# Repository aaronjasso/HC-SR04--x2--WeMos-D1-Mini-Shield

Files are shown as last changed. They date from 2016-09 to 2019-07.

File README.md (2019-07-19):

# HC-SR04--x2--WeMos-D1-Mini-Shield
Shield to attach up to two HC-SR04 ultrasonic distance sensors to a Wemos D1 Mini ESP8266 module.

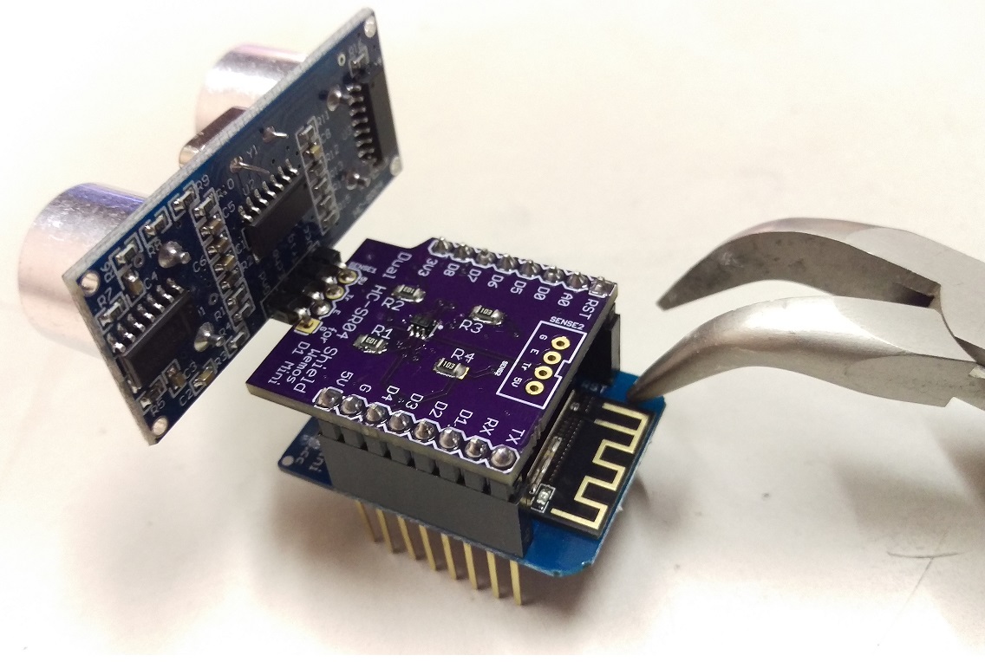
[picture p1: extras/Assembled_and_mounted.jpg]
Assembled Board with SENSE1, mounted to a Wemos D1 Mini


[Sensor datasheet](https://cdn.sparkfun.com/datasheets/Sensors/Proximity/HCSR04.pdf)

[Second datasheet source](https://www.electroschematics.com/8902/hc-sr04-datasheet/)

Works with one or two sensors. The first is mounted to the shield, the second is intended to be mounted elsewhere and connected with a four-conductor cable. It could also be mounted directly to the board facing the opposite direction as the first sensor.

Utilizes a BS138DW SOT-363 chip (which is just two BSS138 N-channel enhanced mode MOSFETs in one package) for level switching the ESP8266's 3.3V trigger pulse up to 5V for the sensors (ref: https://learn.sparkfun.com/tutorials/retired---using-the-logic-level-converter). The down-convert is a simple voltage divider.

All resistors are 0805 size. Resistors on top of board (with the IC) are 10K, resistors on bottom are 20K.

SENSE1 is mounted to the board  
Trigger pin:  D3  
Echo pin:  D4

SENSE2 (optional) can be located off-board  
Trigger pin:  D7  
Echo pin:  D8

The board and SENSE1 have been tested. Example Arduino sketches are in work. Boards available from OSH Park here: https://oshpark.com/shared_projects/YeCIIDGi

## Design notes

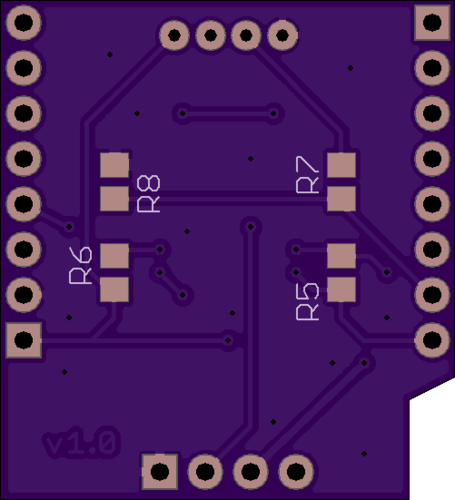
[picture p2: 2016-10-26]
extras/HC-SR04 Shield bottom.png

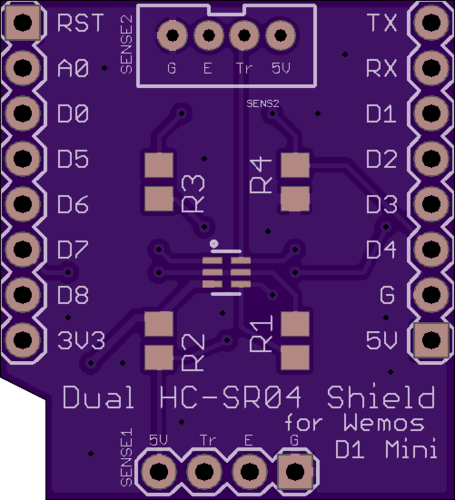
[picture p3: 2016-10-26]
extras/HC-SR04 Shield top.png

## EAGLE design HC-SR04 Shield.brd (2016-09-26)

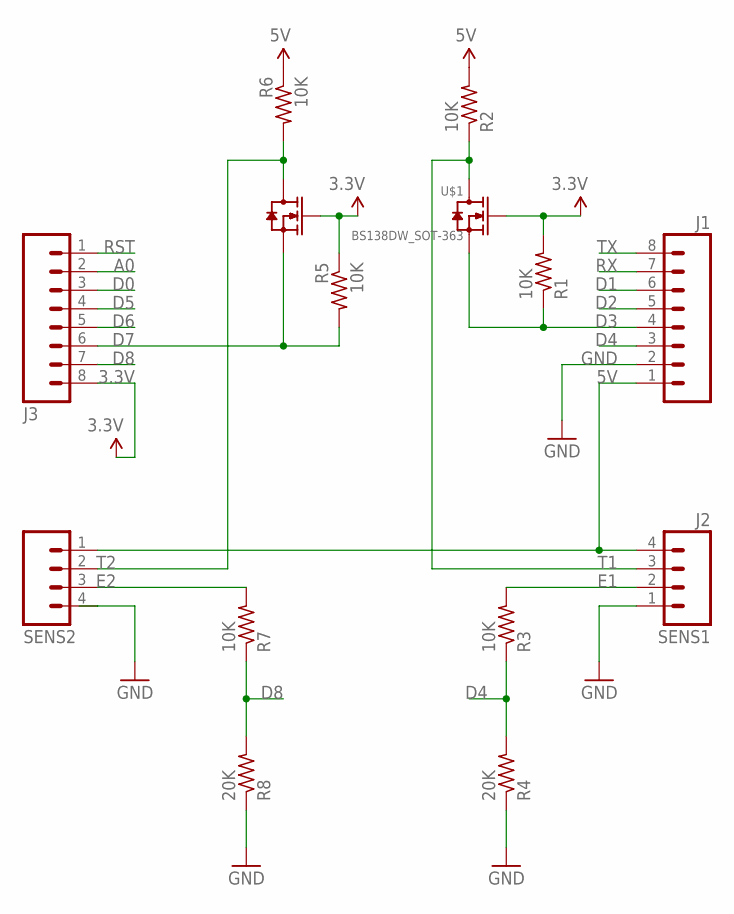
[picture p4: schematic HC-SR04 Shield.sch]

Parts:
J1, J3: M08SILK_FEMALE_PTH; 1X08
J2: SENS1; 1X04
R1, R2, R3, R5, R6, R7: 10K; R0805
R4, R8: 20K; R0805
SENS2: M04JST-PTH-VERT; JST-4-PTH-VERT
U$1: BS138DW_SOT-363; SOT363

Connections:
3.3V: J3.8, R1.2, R5.1, U$1.2 (G1), U$1.5 (G)
5V: J1.1, J2.4, R2.2, R6.1, SENS2.1
A0: J3.2
D0: J3.3
D1: J1.6
D2: J1.5
D3: J1.4, R1.1, U$1.4 (S)
D4: J1.3, R3.1, R4.2
D5: J3.4
D6: J3.5
D7: J3.6, R5.2, U$1.1 (S1)
D8: J3.7, R7.1, R8.2
E1: J2.2, R3.2
E2: R7.2, SENS2.3
GND: J1.2, J2.1, R4.1, R8.1, SENS2.4
RST: J3.1
RX: J1.7
T1: J2.3, R2.1, U$1.3 (D)
T2: R6.2, SENS2.2, U$1.6 (D1)
TX: J1.8

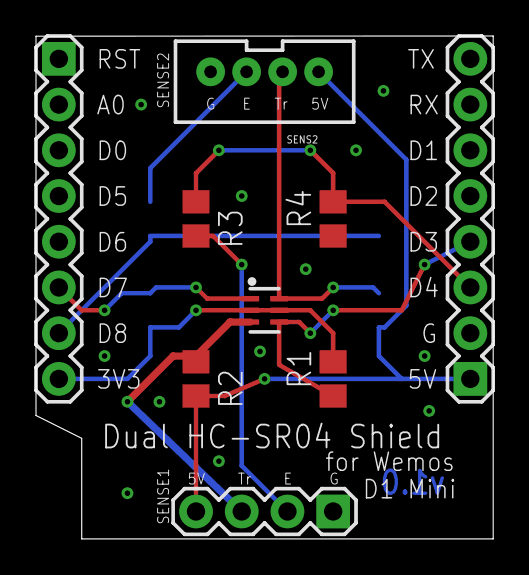
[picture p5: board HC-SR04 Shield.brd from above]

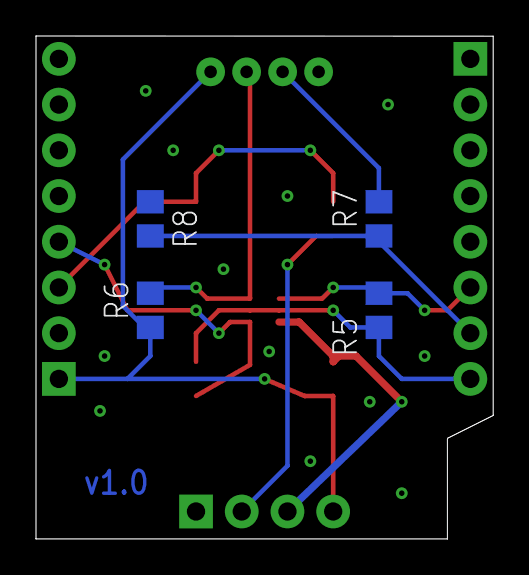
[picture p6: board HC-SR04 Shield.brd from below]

Board: 2 copper layers, 25.4 x 27.9 mm, 13 parts (4 on the bottom side), 11 nets.

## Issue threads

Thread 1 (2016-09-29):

Incorrect header footprint for SENSE2

aaronjasso, 2016-09-29:
SENSE2 is intended to be connected via a JST PH-4 connector. The footprint requires a 0.1" pin pitch, but the existing footprint is something less than 0.1".

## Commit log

2016-09-26 Eagle 7.6.0 files
    [HC-SR04 Shield v1.brd, HC-SR04 Shield v1.sch]
2016-09-28 Initial test Arduino Sketch (in work)
2016-09-28 Remove versions from filenames
    Apparently this is a n00b mistake. Thanks James!
    [HC-SR04 Shield.brd, HC-SR04 Shield.sch]
2016-10-26 Add images
    Created "extras" folder and added images of board top, bottom, and an
    assembled board on a D1 Mini with sensor mounted
2016-10-28 Update README
    Added picture of assembled board

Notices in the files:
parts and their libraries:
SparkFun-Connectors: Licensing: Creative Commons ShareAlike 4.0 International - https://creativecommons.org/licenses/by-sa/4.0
